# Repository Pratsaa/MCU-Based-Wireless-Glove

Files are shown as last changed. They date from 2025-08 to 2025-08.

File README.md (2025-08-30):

# MCU-Based Wireless Glove  

This project is a **wireless gesture-controlled glove** that streams **finger bends (flex sensors)** and **palm motion (IMU)** to a PC, where a Unity application animates a virtual hand in real time.  
- **STM32L031 MCU**: samples and processes sensor data.  
- **ESP32-WROOM**: handles wireless transmission via ESP-NOW.  
- **Python bridge**: ingests and calibrates data, then forwards it to Unity.  
- **Unity C# script**: applies finger and palm movements to a 3D hand model.  

👉 For detailed technical documentation (hardware schematics, PCB design, and system explanation), please see the [Docs/](./Docs) folder.  

---

## 📂 Repository Structure  

MCU-Based-Wireless-Glove/
│
├── Docs/ # Project documentation (ECE395 Final Report + notes)
├── pcb-files/ # PCB schematics, layouts, and related design files
├── src/ # Source code for firmware, PC bridge, and Unity listener
│ ├── stm32/ # STM32 firmware (ADC, IMU SPI, UART output)
│ ├── esp32/ # ESP32 firmware (ESP-NOW wireless bridge, optional IMU polling)
│ ├── python/ # PC-side scripts (serial ingest, calibration, TCP forward)
│ └── unity/ # Unity C# listener scripts (GloveReceiver.cs)
├── placeholder/ # Temporary / unused files (safe to ignore)
├── LICENSE # License information
└── README.md # Project overview (this file)

- **Docs/** – contains the final project report and supporting documents. Start here if you want to understand the full design.  
- **pcb-files/** – all hardware-related design files for the custom PCB.  
- **src/** – source code divided into:  
  - **stm32/** – firmware for STM32L031 MCU (flex sensor ADC, IMU via SPI, UART data framing).  
  - **esp32/** – firmware for ESP32 (wireless data forwarding using ESP-NOW, with optional IMU fallback).  
  - **python/** – PC bridge (`main.py` and helpers) that parses UART data, calibrates sensor values, and forwards JSON over TCP.  
  - **unity/** – Unity scripts (e.g., `GloveReceiver.cs`) that apply incoming data to animate a 3D hand model.  
- **placeholder/** – unused or staging area, not critical to the project.  

---

## ▶️ How It Works  

1. **Sensor acquisition**  
   - Flex sensors + op-amp circuits measure finger bends.  
   - IMU (ICM-20948) provides palm orientation and motion data.  
   - STM32 samples all signals and sends data over UART to the ESP32.  

2. **Wireless bridge**  
   - ESP32 transmits processed sensor data wirelessly to the PC via ESP-NOW.  

3. **PC bridge (Python)**  
   - Parses UART data, calibrates values, and forwards JSON packets over TCP.  

4. **Unity listener**  
   - Receives the data and animates a virtual hand in Unity with low latency.  

---

## 🛠️ Getting Started  

- Build and flash STM32 firmware (inside `src/`).  
- Flash ESP32 firmware (inside `src/`).  
- Run the Python script to ingest sensor data and forward to Unity.  
- Import the Unity C# script into your project to animate the hand.  

**Dependencies:**  
- STM32CubeIDE (or equivalent toolchain)  
- ESP-IDF for ESP32  
- Python 3.x with `pyserial`  
- Unity (2021 LTS or newer recommended)  

---

## 📖 Documentation  

Full documentation and project report can be found in [Docs/](./Docs). This includes:  
- Hardware schematics & PCB design decisions  
- Firmware architecture  
- Python/Unity pipeline  
- Performance metrics and improvements  

---

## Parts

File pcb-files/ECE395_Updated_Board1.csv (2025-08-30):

Reference | Value | Datasheet | Footprint | Qty | DNP | Status
C1,C2,C4,C14,C16 | 0.1uF | ~ | Capacitor_SMD:C_0805_2012Metric_Pad1.18x1.45mm_HandSolder | 5
C5,C6 | 100n | ~ | Capacitor_SMD:C_0805_2012Metric_Pad1.18x1.45mm_HandSolder | 2
C7 | 10n | ~ | Capacitor_SMD:C_0805_2012Metric_Pad1.18x1.45mm_HandSolder | 1
C8,C9 | 1u | ~ | Capacitor_SMD:C_0805_2012Metric_Pad1.18x1.45mm_HandSolder | 2
C10,C13 | 1uF | ~ | Capacitor_SMD:C_0805_2012Metric_Pad1.18x1.45mm_HandSolder | 2
C12,C18 | 100nF | ~ | Capacitor_SMD:C_0805_2012Metric_Pad1.18x1.45mm_HandSolder | 2
C15,C19 | 1.0uF | ~ | Capacitor_SMD:C_0805_2012Metric_Pad1.18x1.45mm_HandSolder | 2
D1 | LED | ~ | LED_SMD:LED_0805_2012Metric_Pad1.15x1.40mm_HandSolder | 1
FB1 | FerriteBead | ~ | Inductor_SMD:L_0805_2012Metric_Pad1.15x1.40mm_HandSolder | 1
J1,J5 | USB_B_Micro | ~ | Connector_USB:USB_Micro-B_Amphenol_10118194-0001LF_Horizontal | 2
J2,J4 | Conn_02x04_Counter_Clockwise | ~ | Connector_PinHeader_2.54mm:PinHeader_2x04_P2.54mm_Vertical | 2
J6,J7,J8,J9 | Conn_01x02_Pin | ~ | Connector_PinHeader_2.54mm:PinHeader_1x02_P2.54mm_Vertical | 4
J13 | Conn_01x04 | ~ | Connector_PinHeader_2.54mm:PinHeader_1x04_P2.54mm_Vertical | 1
Q5,Q6,Q7 | 2N7002 | https://www.onsemi.com/pub/Collateral/NDS7002A-D.PDF | Package_TO_SOT_SMD:SOT-23 | 3
R1,R2,R3 | 10k | ~ | Resistor_SMD:R_0805_2012Metric_Pad1.20x1.40mm_HandSolder | 3
R4,R5,R8,R14 | 47k | ~ | Resistor_SMD:R_0805_2012Metric_Pad1.20x1.40mm_HandSolder | 4
R6,R7,R9,R10,R12,R13,R15,R16 | 4k | ~ | Resistor_SMD:R_0805_2012Metric_Pad1.20x1.40mm_HandSolder | 8
R11,R17 | 1k | ~ | Resistor_SMD:R_0805_2012Metric_Pad1.20x1.40mm_HandSolder | 2
R26,R27,R28,R29,R30,R31 | 2.2k | ~ | Resistor_SMD:R_0805_2012Metric_Pad1.20x1.40mm_HandSolder | 6
RV1,RV2,RV3,RV4 | R_Potentiometer | ~ | Potentiometer_THT:Potentiometer_Bourns_3296W_Vertical | 4
SW1,SW3 | SW_Push | ~ | Button_Switch_THT:SW_PUSH_6mm | 2
TP3 | TestPoint | ~ | TestPoint:TestPoint_2Pads_Pitch2.54mm_Drill0.8mm | 1
U1,U4 | FT232RL | https://www.ftdichip.com/Support/Documents/DataSheets/ICs/DS_FT232R.pdf | Package_SO:SSOP-28_5.3x10.2mm_P0.65mm | 2
U2 | ESP32-WROOM-E | https://www.espressif.com/sites/default/files/documentation/esp32-wroom-32e_esp32-wroom-32ue_datasheet_en.pdf | ESP32 WROOM-E:ESP32-WROOM-32E_EXP | 1
U3 | STM32L031K6Tx | https://www.st.com/resource/en/datasheet/stm32l031k6.pdf | Package_QFP:LQFP-32_7x7mm_P0.8mm | 1
U5 | LM324N | LM324N | LM324N:DIP-14_STM | 1
U6 | TC1262-33 | http://ww1.microchip.com/downloads/en/DeviceDoc/21373C.pdf | Package_TO_SOT_SMD:SOT-223 | 1
U8 | ICM-20948 | http://www.invensense.com/wp-content/uploads/2016/06/DS-000189-ICM-20948-v1.3.pdf | Sensor_Motion:InvenSense_QFN-24_3x3mm_P0.4mm | 1
U10 | AP2112K-1.8 | https://www.diodes.com/assets/Datasheets/AP2112.pdf | Package_TO_SOT_SMD:SOT-23-5 | 1

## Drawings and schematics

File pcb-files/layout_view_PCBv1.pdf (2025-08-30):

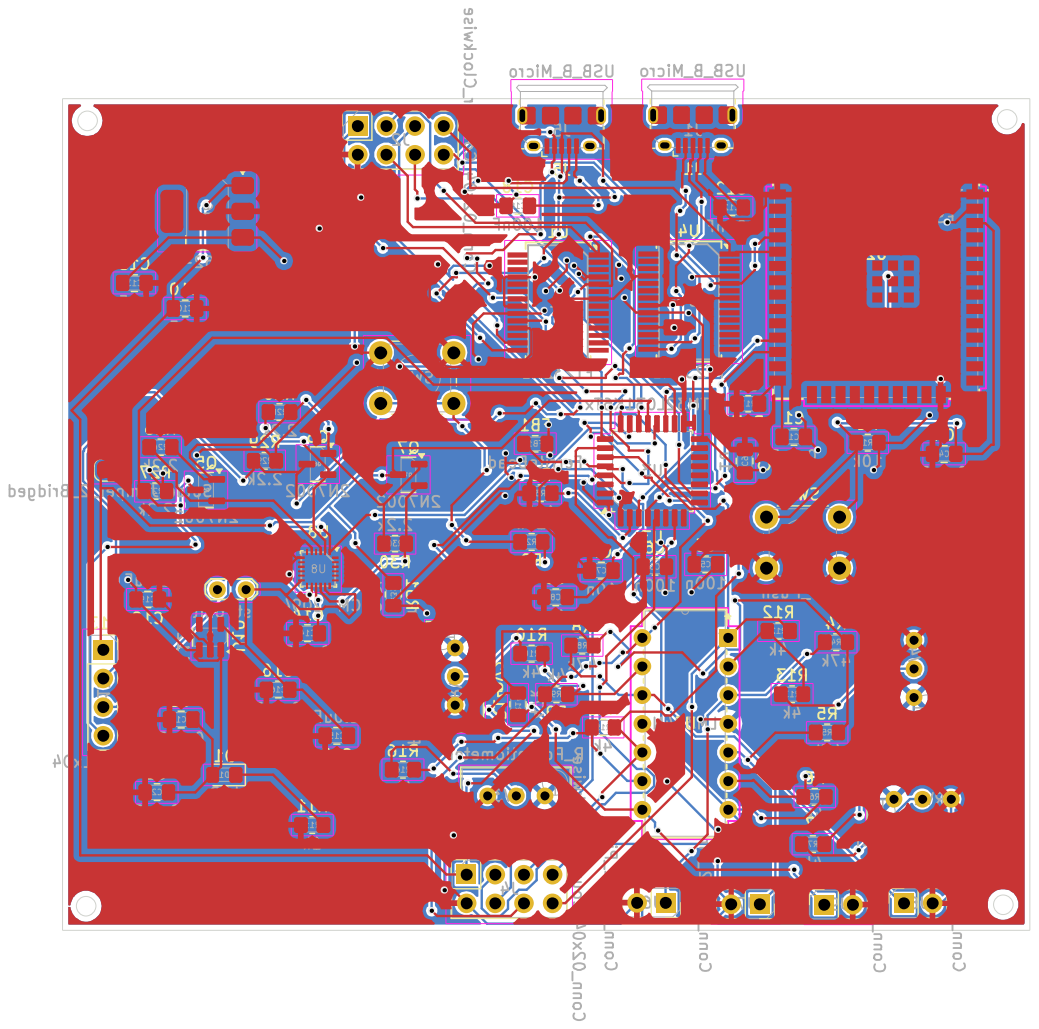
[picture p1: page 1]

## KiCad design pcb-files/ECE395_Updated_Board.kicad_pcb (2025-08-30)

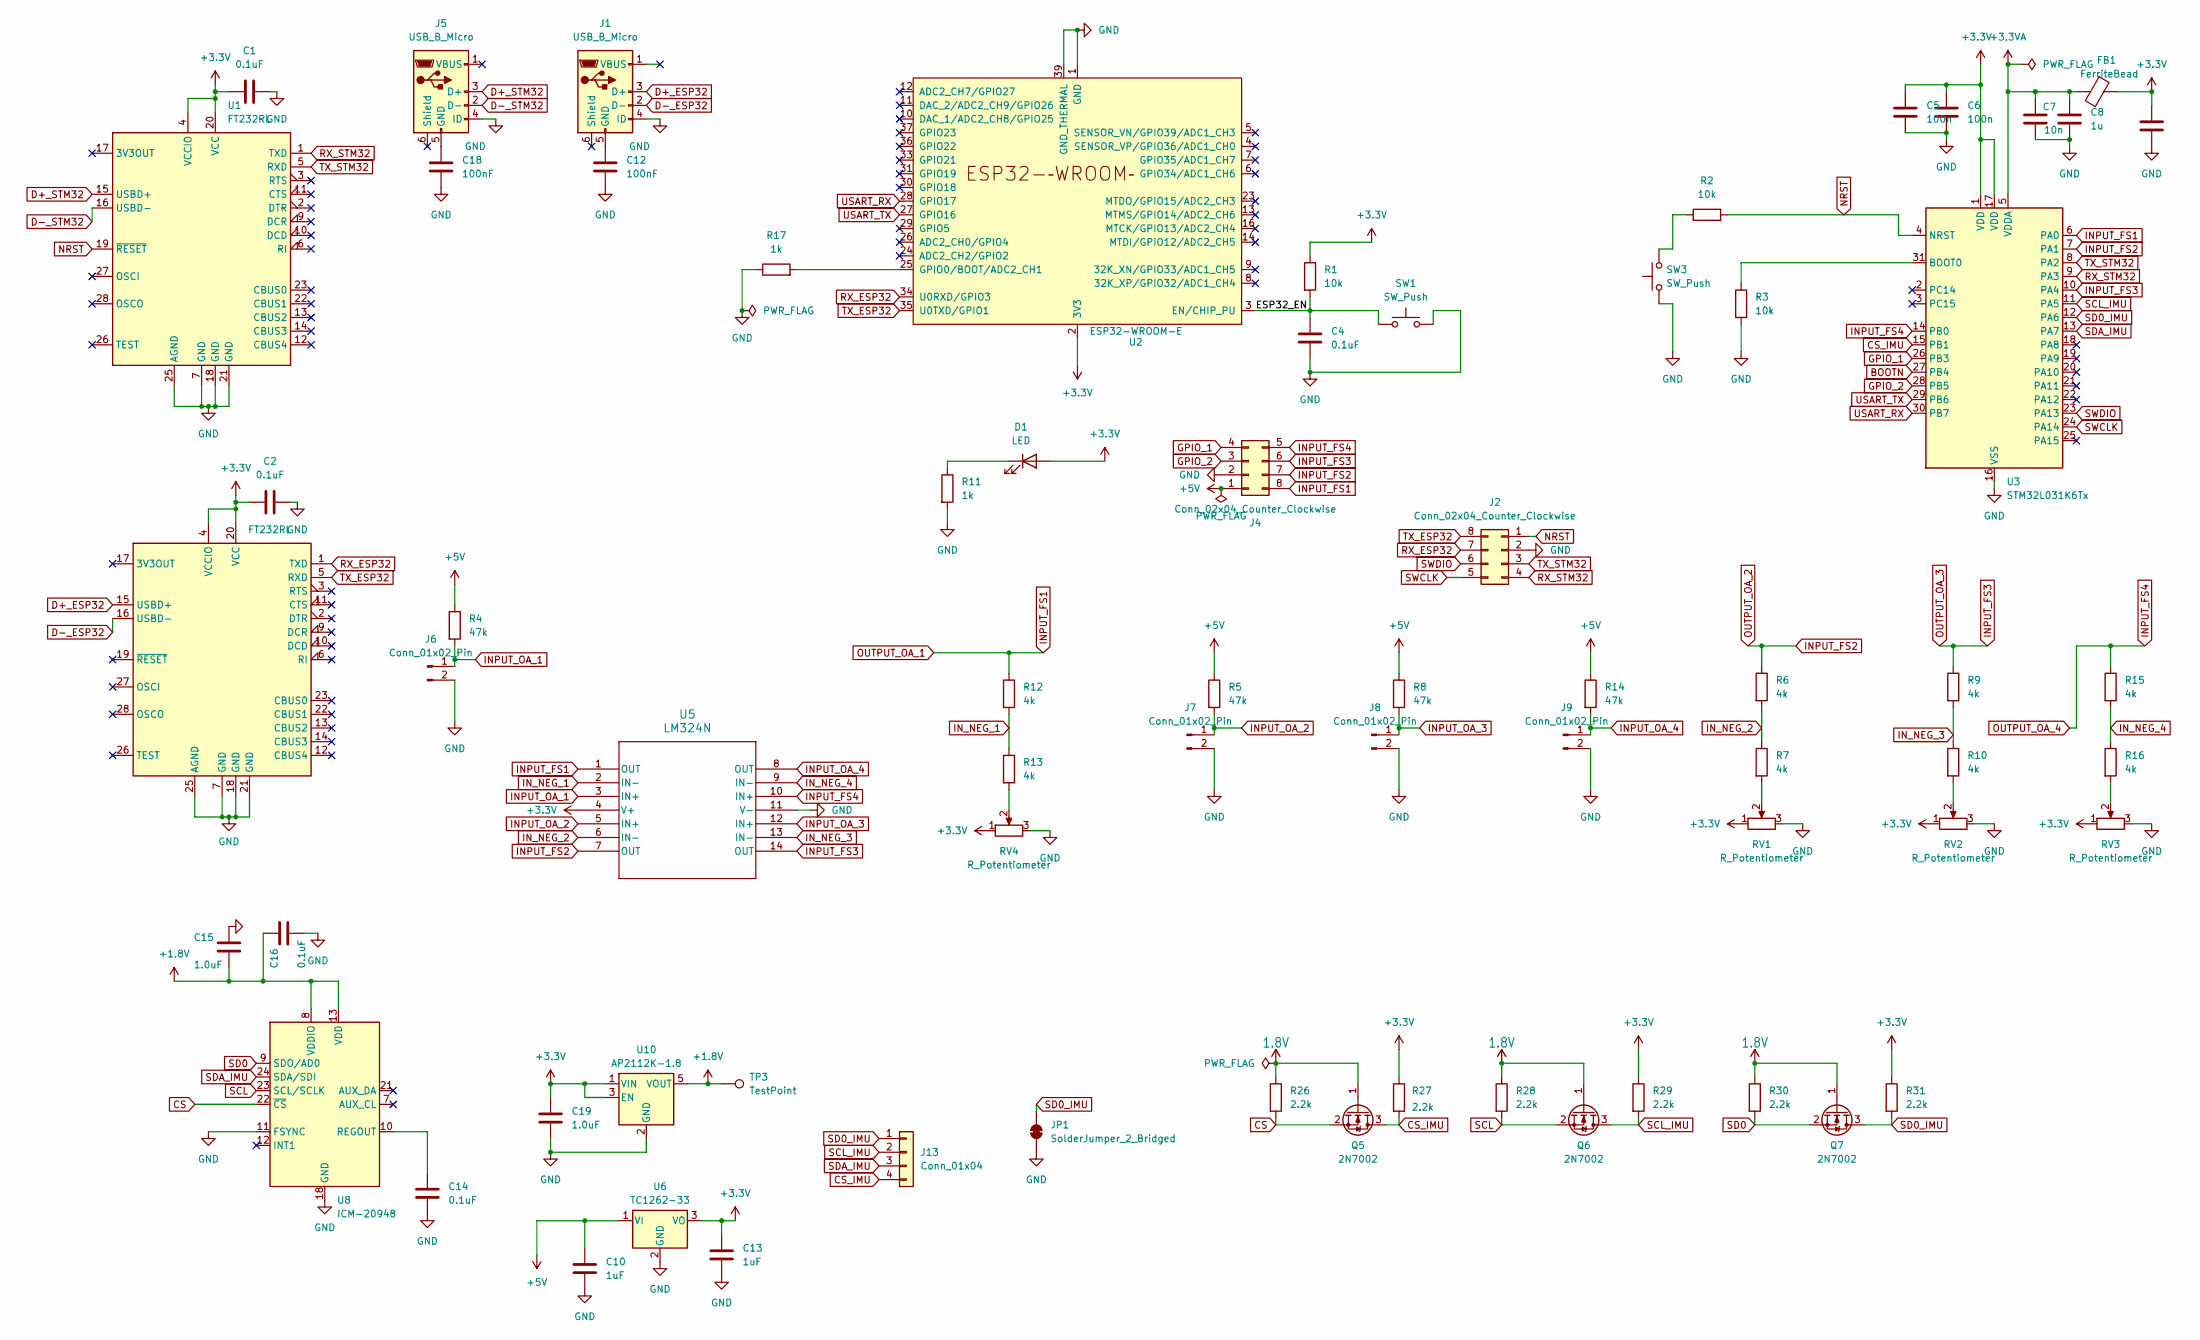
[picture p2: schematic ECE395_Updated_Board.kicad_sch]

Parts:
C1, C2, C4, C14, C16: 0.1uF; C_0805_2012Metric_Pad1.18x1.45mm_HandSolder
C5, C6: 100n; C_0805_2012Metric_Pad1.18x1.45mm_HandSolder
C7: 10n; C_0805_2012Metric_Pad1.18x1.45mm_HandSolder
C8, C9: 1u; C_0805_2012Metric_Pad1.18x1.45mm_HandSolder
C10, C13: 1uF; C_0805_2012Metric_Pad1.18x1.45mm_HandSolder
C12, C18: 100nF; C_0805_2012Metric_Pad1.18x1.45mm_HandSolder
C15, C19: 1.0uF; C_0805_2012Metric_Pad1.18x1.45mm_HandSolder
D1: LED; LED_0805_2012Metric_Pad1.15x1.40mm_HandSolder
FB1: FerriteBead; L_0805_2012Metric_Pad1.15x1.40mm_HandSolder
J1, J5: USB_B_Micro; USB_Micro-B_Amphenol_10118194-0001LF_Horizontal
J2, J4: Conn_02x04_Counter_Clockwise; PinHeader_2x04_P2.54mm_Vertical
J6, J7, J8, J9: Conn_01x02_Pin; PinHeader_1x02_P2.54mm_Vertical
J13: Conn_01x04; PinHeader_1x04_P2.54mm_Vertical
JP1: SolderJumper_2_Bridged; SolderJumper-2_P1.3mm_Bridged_RoundedPad1.0x1.5mm
Q5, Q6, Q7: 2N7002; SOT-23
R1, R2, R3: 10k; R_0805_2012Metric_Pad1.20x1.40mm_HandSolder
R4, R5, R8, R14: 47k; R_0805_2012Metric_Pad1.20x1.40mm_HandSolder
R6, R7, R9, R10, R12, R13, R15, R16: 4k; R_0805_2012Metric_Pad1.20x1.40mm_HandSolder
R11, R17: 1k; R_0805_2012Metric_Pad1.20x1.40mm_HandSolder
R26, R27, R28, R29, R30, R31: 2.2k; R_0805_2012Metric_Pad1.20x1.40mm_HandSolder
RV1, RV2, RV3, RV4: R_Potentiometer; Potentiometer_Bourns_3296W_Vertical
SW1, SW3: SW_Push; SW_PUSH_6mm
TP3: TestPoint; TestPoint_2Pads_Pitch2.54mm_Drill0.8mm
U1, U4: FT232RL; SSOP-28_5.3x10.2mm_P0.65mm
U2: ESP32-WROOM-E; ESP32­WROOM­32E_EXP
U3: STM32L031K6Tx; LQFP-32_7x7mm_P0.8mm
U5: LM324N; DIP-14_STM
U6: TC1262-33; SOT-223
U8: ICM-20948; InvenSense_QFN-24_3x3mm_P0.4mm
U10: AP2112K-1.8; SOT-23-5

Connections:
1.8V: Q5.1 (G), Q6.1 (G), Q7.1 (G), R26.1, R28.1, R30.1
+1.8V: C15.2, C16.1, TP3.1, U8.8 (VDDIO), U8.13 (VDD), U10.5 (VOUT)
+3.3V: C1.1, C2.1, C5.1, C6.1, C9.1, C13.2, C19.1, D1.2 (A), FB1.1, R1.1, R27.1, R29.1, R31.1, RV1.1, RV2.1, RV3.1, RV4.1, U1.4 (VCCIO), U1.20 (VCC), U2.2 (3V3), U3.1 (VDD), U3.17 (VDD), U4.4 (VCCIO), U4.20 (VCC), U5.4 (V+), U6.3 (VO), U10.1 (VIN), U10.3 (EN); also elsewhere on the board
+3.3VA: C7.1, C8.1, FB1.2, U3.5 (VDDA)
+5V: C10.2, J4.1, R4.1, R5.1, R8.1, R14.1, U6.1 (VI)
/ESP32_EN: C4.1, R1.2, SW1.1, U2.3 (EN/CHIP_PU)
BOOTN: U3.27 (PB4)
CS: Q5.2 (S), R26.2, U8.22 (~CS)
CS_IMU: J13.4, Q5.3 (D), R27.2, U3.15 (PB1)
D+_ESP32: J1.3 (D+), U4.15 (USBD+)
D+_STM32: J5.3 (D+), U1.15 (USBD+)
D-_ESP32: J1.2 (D-), U4.16 (USBD-)
D-_STM32: J5.2 (D-), U1.16 (USBD-)
GND: C1.2, C2.2, C4.2, C5.2, C6.2, C7.2, C8.2, C9.2, C10.1, C12.2, C13.1, C14.2, C15.1, C16.2, C18.2, C19.2, J1.4 (ID), J2.2, J4.2, J5.4 (ID), J6.2, J7.2, J8.2, J9.2, JP1.1 (A), R3.2, R11.2, R17.1, RV1.3, RV2.3, RV3.3, RV4.3, SW1.2, SW3.1, U1.7 (GND), U1.18 (GND), U1.21 (GND), U1.25 (AGND), U2.1 (GND), U2.15 (GND), U2.38 (GND), U2.39 (GND_THERMAL), U3.16 (VSS), U3.32 (VSS), U4.7 (GND), U4.18 (GND), U4.21 (GND), U4.25 (AGND), U5.11 (V-), U6.2 (GND), U8.11 (FSYNC), U8.18 (GND), U8.20 (GND), U10.2 (GND)
GPIO_1: J4.4, U3.26 (PB3)
GPIO_2: J4.3, U3.28 (PB5)
INPUT_FS1: J4.8, R12.1, U3.6 (PA0), U5.1 (OUT)
INPUT_FS2: J4.7, R6.1, U3.7 (PA1), U5.7 (OUT)
INPUT_FS3: J4.6, R9.1, U3.10 (PA4), U5.14 (OUT)
INPUT_FS4: J4.5, R15.1, U3.14 (PB0), U5.10 (IN+)
INPUT_OA_1: J6.1, R4.2, U5.3 (IN+)
INPUT_OA_2: J7.1, R5.2, U5.5 (IN+)
INPUT_OA_3: J8.1, R8.2, U5.12 (IN+)
INPUT_OA_4: J9.1, R14.2, U5.8 (OUT)
IN_NEG_1: R12.2, R13.1, U5.2 (IN-)
IN_NEG_2: R6.2, R7.1, U5.6 (IN-)
IN_NEG_3: R9.2, R10.1, U5.13 (IN-)
IN_NEG_4: R15.2, R16.1, U5.9 (IN-)
NRST: J2.1, R2.2, U1.19 (~RESET), U3.4 (NRST)
unnamed: D1.1 (K), R11.1
unnamed: C12.1, J1.5 (GND)
unnamed: C18.1, J5.5 (GND)
unnamed: R2.1, SW3.2
unnamed: R7.2, RV1.2
unnamed: R10.2, RV2.2
unnamed: R13.2, RV4.2
unnamed: R16.2, RV3.2
unnamed 37: R17.2, U2.25 (GPIO0/BOOT/ADC2_CH1); also elsewhere on the board
unnamed: R3.1, U3.31 (BOOT0)
unnamed: C14.1, U8.10 (REGOUT)
RX_ESP32: J2.7, U2.34 (U0RXD/GPIO3), U4.1 (TXD)
RX_STM32: J2.4, U1.1 (TXD), U3.9 (PA3)
SCL: Q6.2 (S), R28.2, U8.23 (SCL/SCLK)
SCL_IMU: J13.2, Q6.3 (D), R29.2, U3.11 (PA5)
SD0: Q7.2 (S), R30.2, U8.9 (SDO/AD0)
SD0_IMU: J13.1, JP1.2 (B), Q7.3 (D), R31.2, U3.12 (PA6)
SDA_IMU: J13.3, U3.13 (PA7), U8.24 (SDA/SDI)
SWCLK: J2.5, U3.24 (PA14)
SWDIO: J2.6, U3.23 (PA13)
TX_ESP32: J2.8, U2.35 (U0TXD/GPIO1), U4.5 (RXD)
TX_STM32: J2.3, U1.5 (RXD), U3.8 (PA2)
USART_RX: U2.28 (GPIO17), U3.30 (PB7)
USART_TX: U2.27 (GPIO16), U3.29 (PB6)

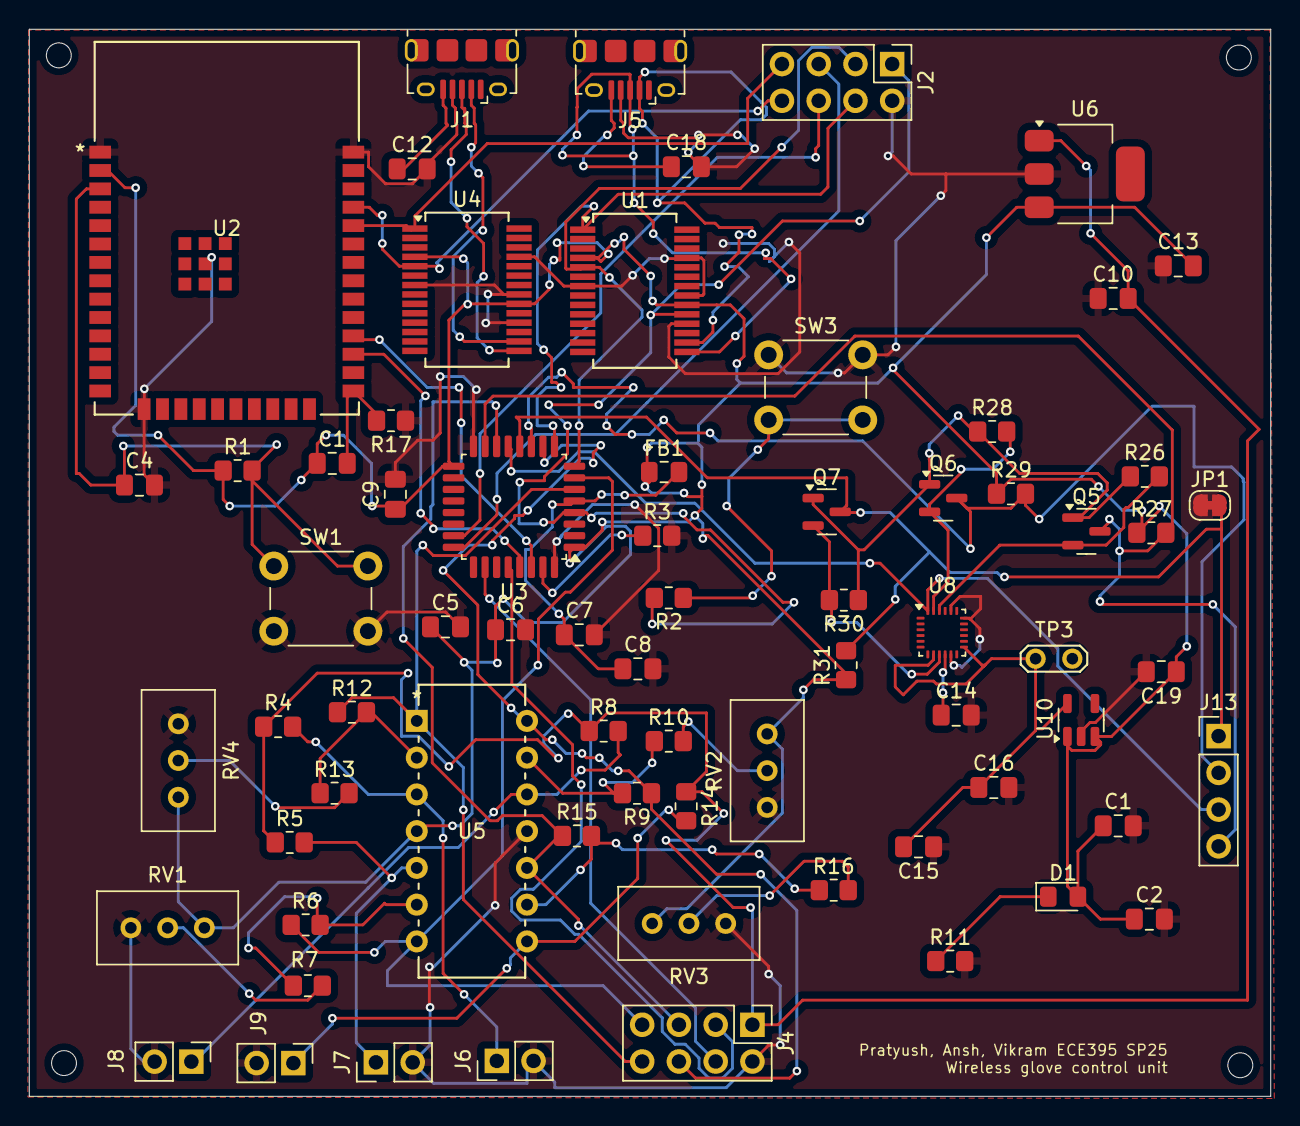
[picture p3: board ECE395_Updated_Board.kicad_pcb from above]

Board: 2 copper layers, 85.8 x 73.8 mm, 70 parts (0 on the bottom side), 52 nets.

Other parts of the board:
C1#2: 0.1uF; C_0805_2012Metric_Pad1.18x1.45mm_HandSolder

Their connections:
+3.3V: C1#2.1; also elsewhere on the board
unnamed 37: C1#2.2; also elsewhere on the board

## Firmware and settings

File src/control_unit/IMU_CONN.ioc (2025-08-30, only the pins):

Mcu.UserName=STM32L031K6Tx
PA0-CK_IN.Signal=ADC_IN0
PA1.Signal=ADC_IN1
PA10.Signal=I2C1_SDA
PA11.Signal=SPI1_MISO
PA2.Signal=LPUART1_TX
PA3.Signal=LPUART1_RX
PA4.Signal=ADC_IN4
PA5.Signal=SPI1_SCK
PA7.Signal=SPI1_MOSI
PA9.Signal=I2C1_SCL
PB1.GPIO_Label=SPI1_CSS
PB1.Signal=GPIO_Output
PB6.Signal=USART2_TX
PB7.Signal=USART2_RX

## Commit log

2025-08-18 Initial commit: wireless MCU glove
2025-08-21 Added all the wireless bridge (python) files used
2025-08-21 Renamed folder to wireless-bridge-files
2025-08-21 Updated all the wireless bridge (python) files
2025-08-30 latest pcb files
